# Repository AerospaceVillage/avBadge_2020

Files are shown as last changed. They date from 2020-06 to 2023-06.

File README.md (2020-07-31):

# Aerospace Village Badge 2020

This resository is to document and capture all of the engineering and design work that went into creating the [Aerospace Village](https://aerospacevillage.org) Badge for 2020.

The badge is a multifunctional design that is part SWAG, part antenna, part low level protocol interaction. In keeping with the spirit of aviation everything is as small as possible and tries to use as much of the available resources as possible.

You can even use this airplane shaped badge as an anetenna to locate real airplanes transmitting ADS-B. Additionally, you can also use it to capture data from other freqenices (i.e. ACARS) using the built in SMA to wire terminal blocks. Why stop there? You can also interact with your preferred I2C device ([bus pirate](https://learn.sparkfun.com/tutorials/bus-pirate-v36a-hookup-guide/all#introduction)) and control each of the available lighting packages. Alternatively, you could just wear it and look cool.

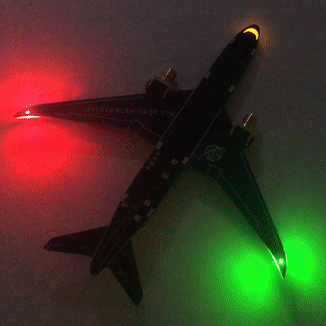
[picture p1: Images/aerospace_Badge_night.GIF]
 

## Kit Assembly

Instructions for assembing a kit can be found in the Document folder.
    
  - [Tindie Instructions](https://github.com/daneallen/avBadge_2020/blob/master/Documents/Tindie%20Instructions.pdf)
  - [Instructions sent with kit](https://github.com/daneallen/avBadge_2020/blob/master/Documents/Send%20out%20instructions.pdf)

## Arduino Programming
Using the Arduino IDE Add the correct Boards Manager URL:

    - Under File->Preferences add the following URL http://drazzy.com/package_drazzy.com_index.json
    - Then with the new Boards Maanger options select ATTinyCore

Steps:

    - Programmer - USBTinyISP
    - Clock 8MHZ
    - Burn Bootloader
    - Upload using programmer

## AVR Programming

[device permissions help](https://andreasrohner.at/posts/Electronics/How-to-fix-device-permissions-for-the-USBasp-programmer/)

[ttyACM permission](https://stackoverflow.com/questions/40951728/avrdude-ser-open-cant-open-device-dev-ttyacm0-device-or-resource-busy)

```
sudo adduser <username> dialout
$ sudo chmod a+rw /dev/ttyACM0
```

## Hardware
The ATtiny85 is programmed with the [Sparkfun Tiny AVR Programmer](https://www.sparkfun.com/products/11801) using the [SparkFun ISP Pogo Adapter](https://www.sparkfun.com/products/11591)

## Lanyard Modification
Check out the .stl files in the /sma lanyard folder that you can print to more easily turn the badge into a wearable lanyard.



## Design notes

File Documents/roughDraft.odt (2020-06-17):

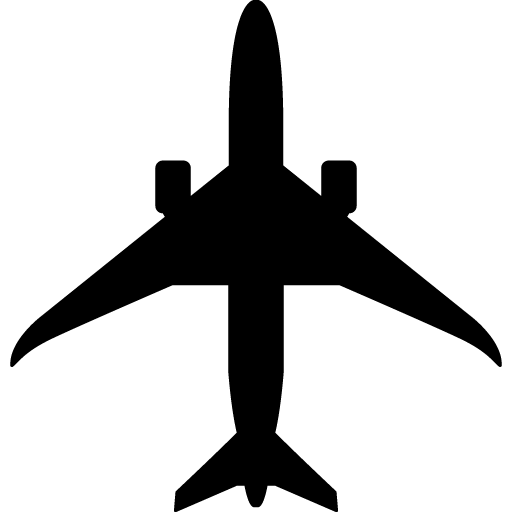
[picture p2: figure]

SMA Connector

RED LED

White Cockpit LED

All LEDs reverse mounted

PCB Antenna

Anti Collision LED - flashing

GREEN LED

Anti Collision LED - flashing

Dipole antenna setup

total length ~14cm

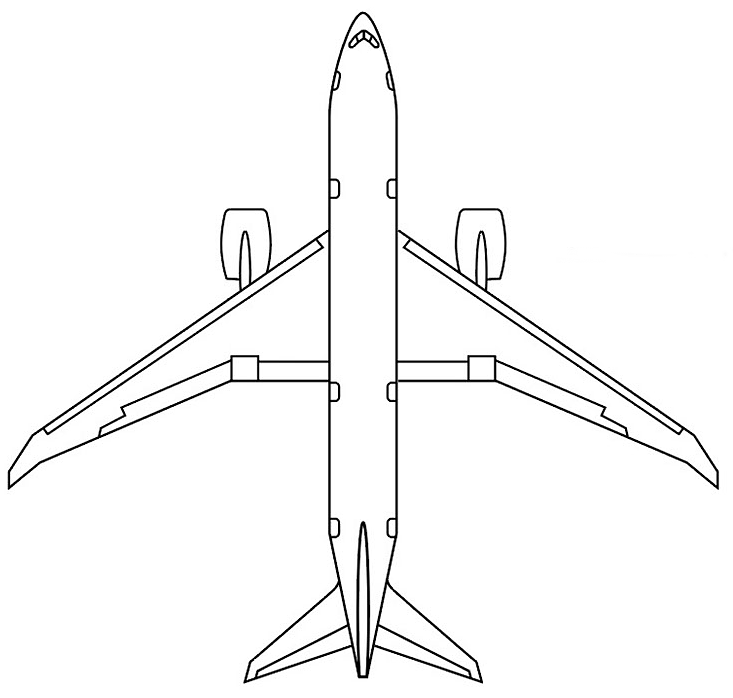
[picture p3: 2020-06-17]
Images/boeingDreamliner.png

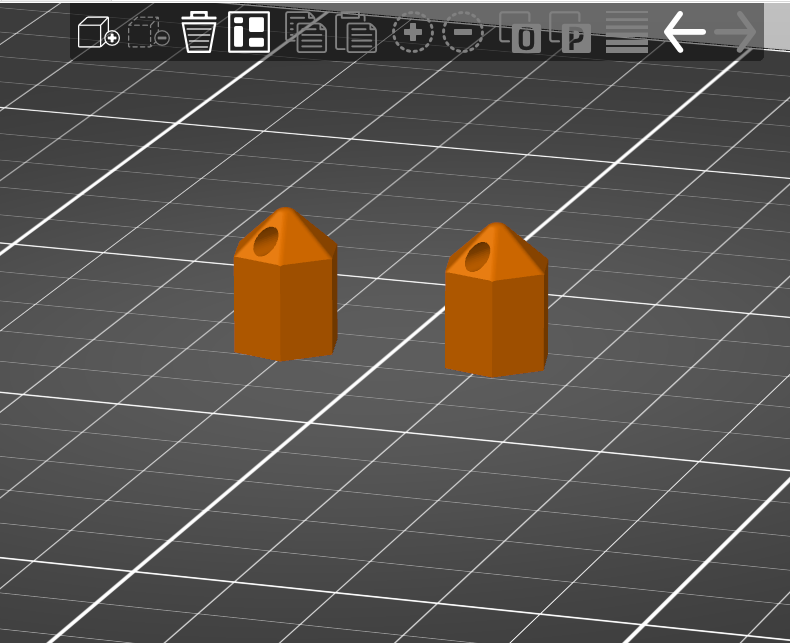
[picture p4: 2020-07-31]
sma lanyard/smaplug_caplanyard.png

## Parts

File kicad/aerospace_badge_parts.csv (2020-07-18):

Reference | Value | Notes | Footprint
BT1 | Battery_Cell |  | Battery:BatteryHolder_Keystone_3034_1x20mm
D1 | LED | Yellow - Flightdeck | sunled:XZMYK45WT-9
D2 | LED | Green – Navigation | sunled:XZDGK45WT-9
D3 | LED | Red – Navigation | sunled:XZM2CRK45WT-9
D4-D5 | LED | Anti-Collision White | aerospace_badge:led_in-s124ar
J1-J2 | Conn_01x02 | SMA Connector | aerospace_badge:linx_sma_jack_female_socket
J6-J7 | Conn_01x01_Male | Wire Terminal push button | aerospace_badge:wire_terminal_sr99s01
R1-R5 | 330 Ohms | Resistor | Resistors_SMD:R_1206_3216Metric
SW1 | SW_SPDT | Power Switch | aerospace_badge:switch_JS202011SCQN
U1 | ATtiny85-20SU | Microcontroller | Package_SO:SOIJ-8_5.3x5.3mm_P1.27mm

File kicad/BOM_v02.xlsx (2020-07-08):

Manufacturer Part Number | Manufacturer | Digi-Key Part Number | Customer Reference | Reference Designator | Packaging | Part Status | Quantity | Unit Price | Extended Price | Quantity Available | Mfg Std Lead Time | Description | RoHS Status | Lead Free Status | REACH Status
CONSMA020.062-G | Linx Technologies Inc. | 343-CONSMA020.062-G-ND |  |  | Tray | Active | 2 | 2.96 | $5.92 | 3094 | 12 Weeks | CONN SMA FML EDGE MNT 0.062" PCB | ROHS3 Compliant | Lead free | Not Available
XZM2CRK45WT-9 | SunLED | 1497-1332-1-ND |  |  | Cut Tape (CT) | Active | 1 | 0.66 | $0.66 | 1772 | 12 Weeks | LED RED CLEAR 2PLCC SMD | ROHS3 Compliant | Lead free | REACH Unaffected
XZDGK45WT-9 | SunLED | 1497-1337-1-ND |  |  | Cut Tape (CT) | Active | 1 | 0.74 | $0.74 | 98154 | 12 Weeks | LED GREEN CLEAR 2PLCC | ROHS3 Compliant | Lead free | Not Available
XZMYK45WT-9 | SunLED | 1497-1334-1-ND |  |  | Cut Tape (CT) | Active | 1 | 0.54 | $0.54 | 21238 | 12 Weeks | LED YELLOW CLEAR 2PLCC SMD | ROHS3 Compliant | Lead free | REACH Unaffected
RC1206FR-07330RL | Yageo | 311-330FRCT-ND |  |  | Cut Tape (CT) | Active | 5 | 0.1 | $0.50 | 31990 | 24 Weeks | RES SMD 330 OHM 1% 1/4W 1206 | ROHS3 Compliant | Lead free | REACH Unaffected
ATTINY85-20SUR | Microchip Technology | ATTINY85-20SURCT-ND |  |  | Cut Tape (CT) | Active | 1 | 1.19 | $1.19 | 8552 | 17 Weeks | IC MCU 8BIT 8KB FLASH 8SOIC | ROHS3 Compliant | Lead free | REACH Unaffected
3034 | Keystone Electronics | 36-3034-ND |  |  | Bulk | Active | 1 | 0.31 | $0.31 | 5529 | 6 Weeks | BATTERY RETAINER COIN 20MM SMD | ROHS3 Compliant | Lead free | REACH Unaffected
IN-S124ARUW | Inolux | 1830-1119-1-ND |  |  | Cut Tape (CT) | Active | 2 | 0.41 | $0.82 | 17759 | 6 Weeks | LED WHITE CLEAR 1204 SMD | ROHS3 Compliant | Lead free | Not Available
SR99S01VBNN00G7 | METZ CONNECT USA Inc. | 1849-1167-1-ND |  |  | Cut Tape (CT) | Active | 2 | 1.16 | $2.32 | 6098 | 15 Weeks | TERM BLOCK 1POS SIDE ENTRY PCB | RoHS Compliant | Lead free | Not Available
JS202011SCQN | C&K | 401-2002-1-ND |  |  | Cut Tape (CT) | Active | 1 | 0.6 | $0.60 | 30511 | 13 Weeks | SWITCH SLIDE DPDT 300MA 6V | ROHS3 Compliant | Lead free | REACH Unaffected

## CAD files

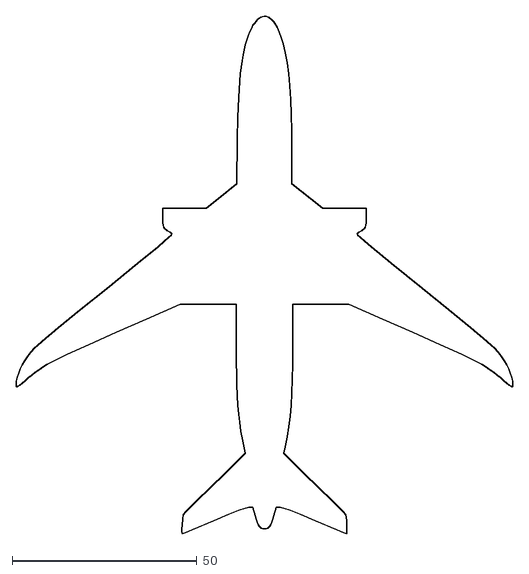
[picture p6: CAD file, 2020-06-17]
Images/boeing787.dxf
134.3 x 140.0

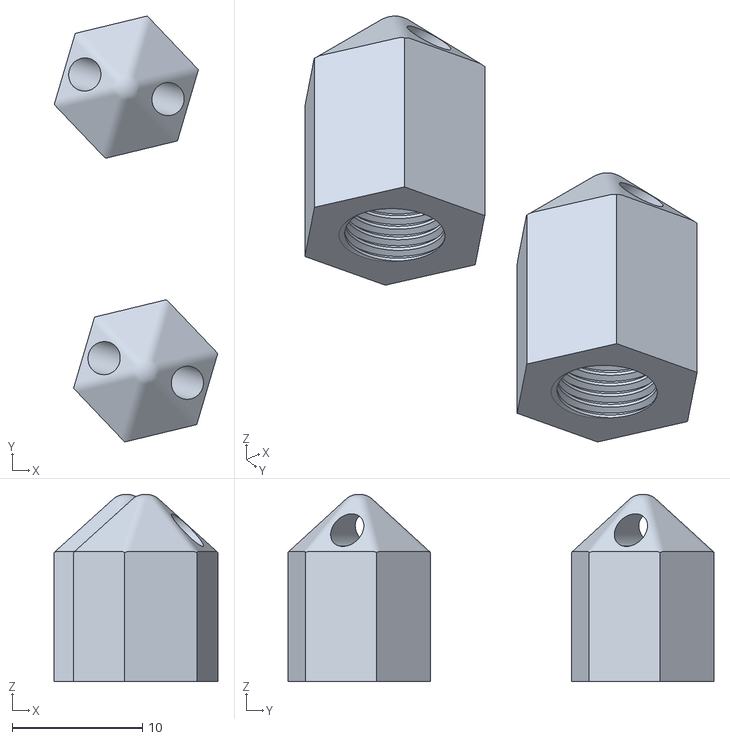
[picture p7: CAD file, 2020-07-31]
sma lanyard/smaplug_aero.stl
12.5 x 32.7 x 14.4

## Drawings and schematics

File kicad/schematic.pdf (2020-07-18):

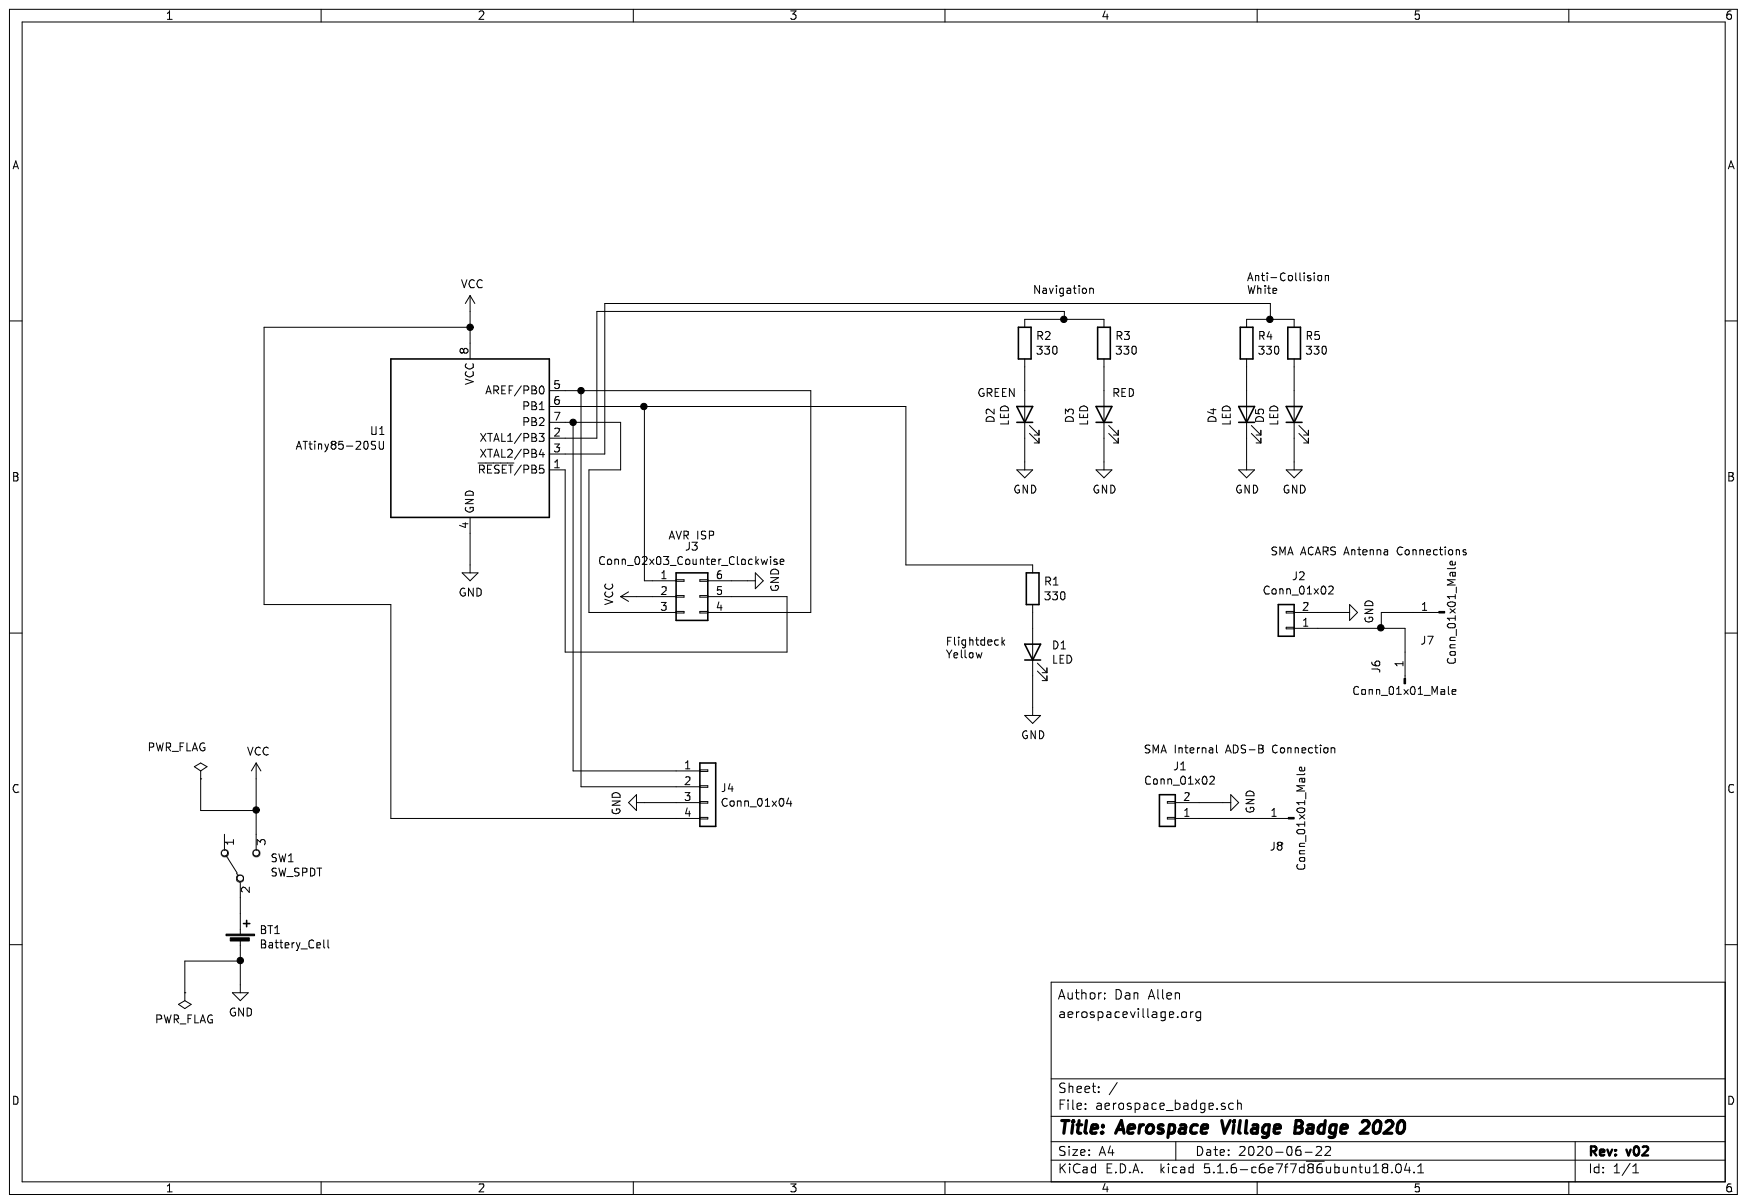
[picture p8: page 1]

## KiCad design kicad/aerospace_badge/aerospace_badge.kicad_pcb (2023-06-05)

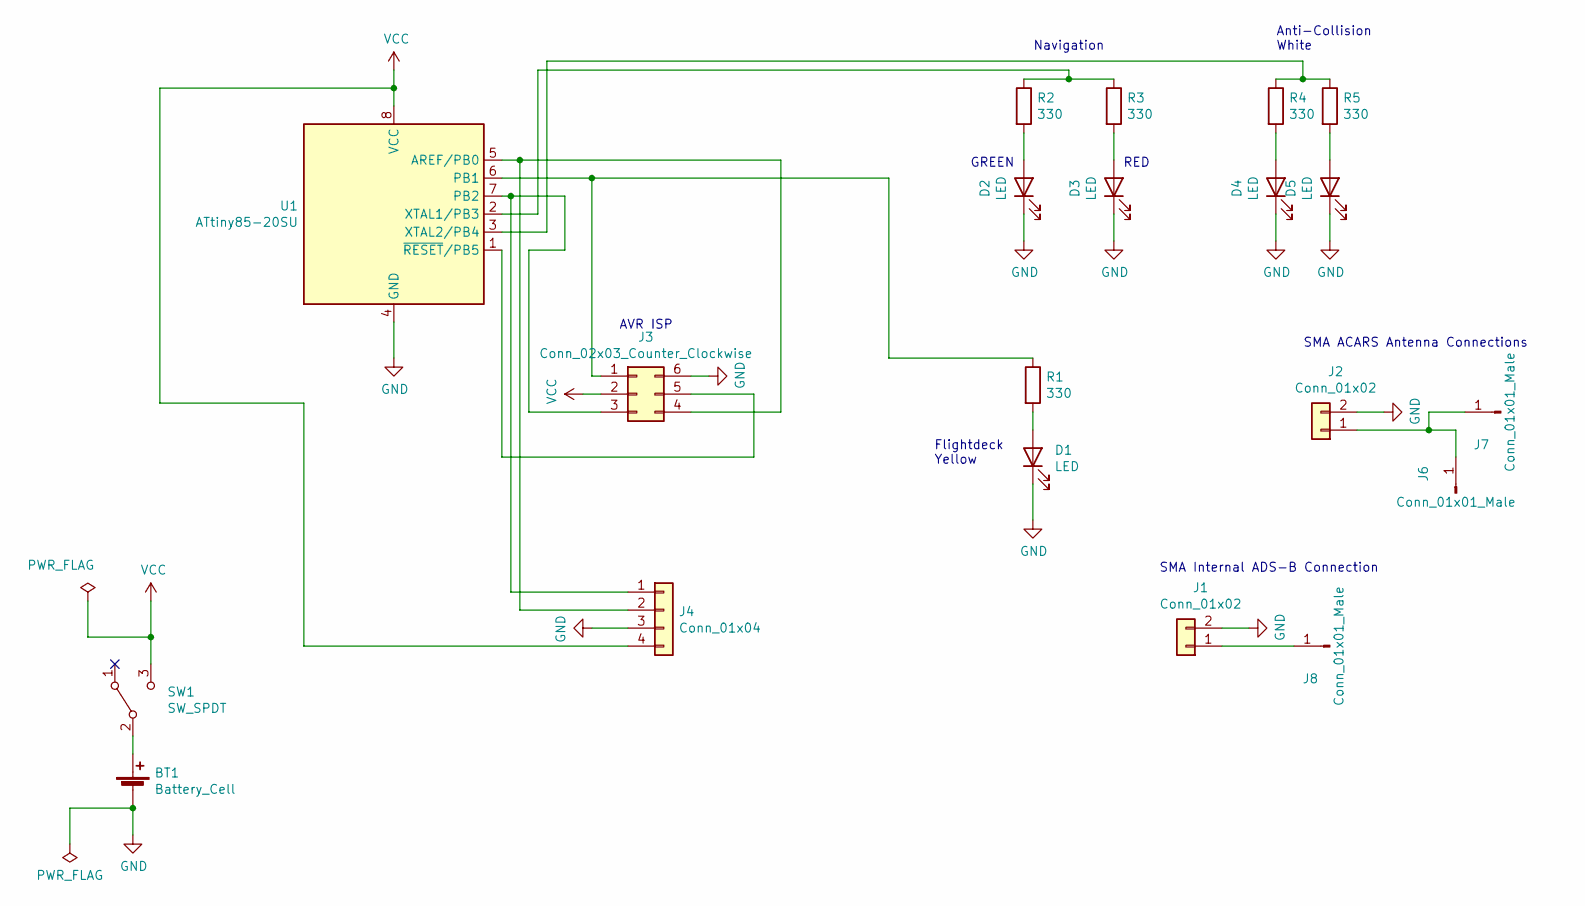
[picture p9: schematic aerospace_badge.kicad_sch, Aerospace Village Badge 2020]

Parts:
BT1: Battery_Cell; BatteryHolder_Keystone_3034_1x20mm
D1: LED; XZMYK45WT-9
D2: LED; XZDGK45WT-9
D3: LED; XZM2CRK45WT-9
D4, D5: LED; led_in-s124ar
J1, J2: Conn_01x02; linx_sma_jack_female_socket
J3: Conn_02x03_Counter_Clockwise; isp_pad
J4: Conn_01x04; PinHeader_1x04_P2.54mm_Vertical
J6, J7: Conn_01x01_Male; wire_terminal_sr99s01
J8: Conn_01x01_Male; badge_v02
R1, R2, R3, R4, R5: 330; R_1206_3216Metric
SW1: SW_SPDT; switch_JS202011SCQN
U1: ATtiny85-20SU; SOIJ-8_5.3x5.3mm_P1.27mm

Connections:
GND: BT1.2 (-), D1.1 (K), D2.1 (K), D3.1 (K), D4.1 (K), D5.1 (K), J1.2, J2.2, J3.6, J4.3, U1.4 (GND)
unnamed: BT1.1 (+), SW1.2 (B)
unnamed: D1.2 (A), R1.2
unnamed: D2.2 (A), R2.2
unnamed: D3.2 (A), R3.2
unnamed: D4.2 (A), R4.2
unnamed: D5.2 (A), R5.2
unnamed: J1.1, J8.1
unnamed: J2.1, J6.1, J7.1
unnamed: J3.1, R1.1, U1.6 (PB1)
unnamed: J3.3, J4.1, U1.7 (PB2)
unnamed: J3.4, J4.2, U1.5 (AREF/PB0)
unnamed: J3.5, U1.1 (~RESET/PB5)
unnamed: R2.1, R3.1, U1.2 (XTAL1/PB3)
unnamed: R4.1, R5.1, U1.3 (XTAL2/PB4)
VCC: J3.2, J4.4, SW1.3 (C), U1.8 (VCC)

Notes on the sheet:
SMA Internal ADS-B Connection
Anti-Collision White
AVR ISP
Navigation
SMA ACARS Antenna Connections
Flightdeck Yellow
RED
GREEN

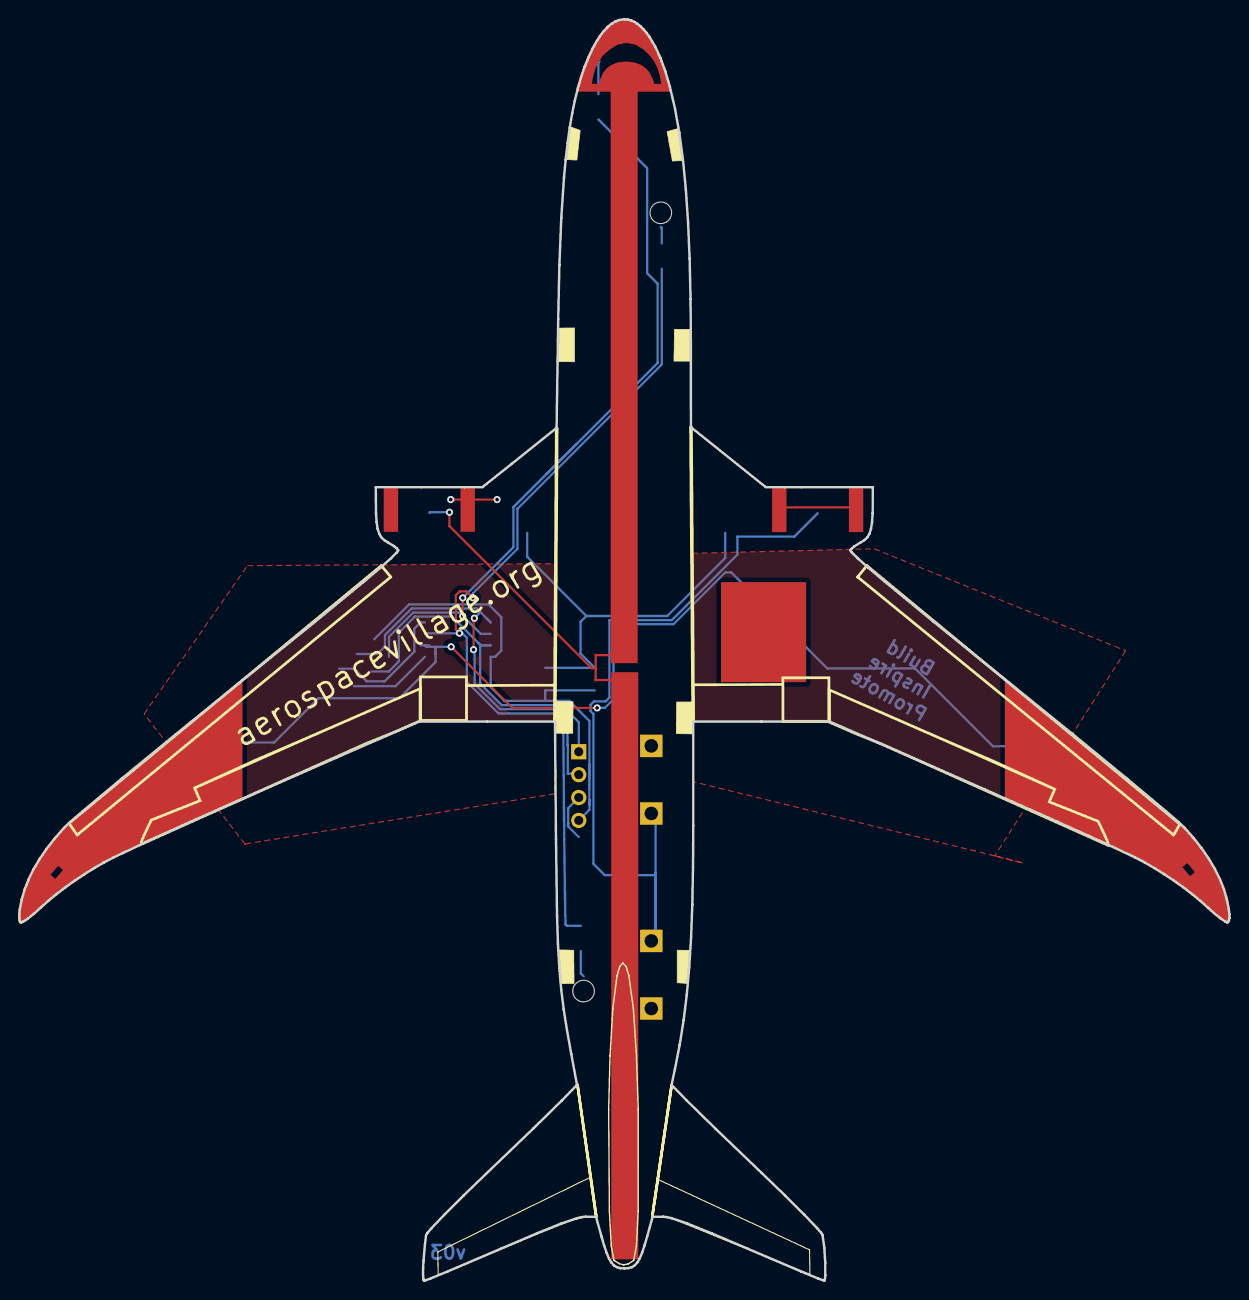
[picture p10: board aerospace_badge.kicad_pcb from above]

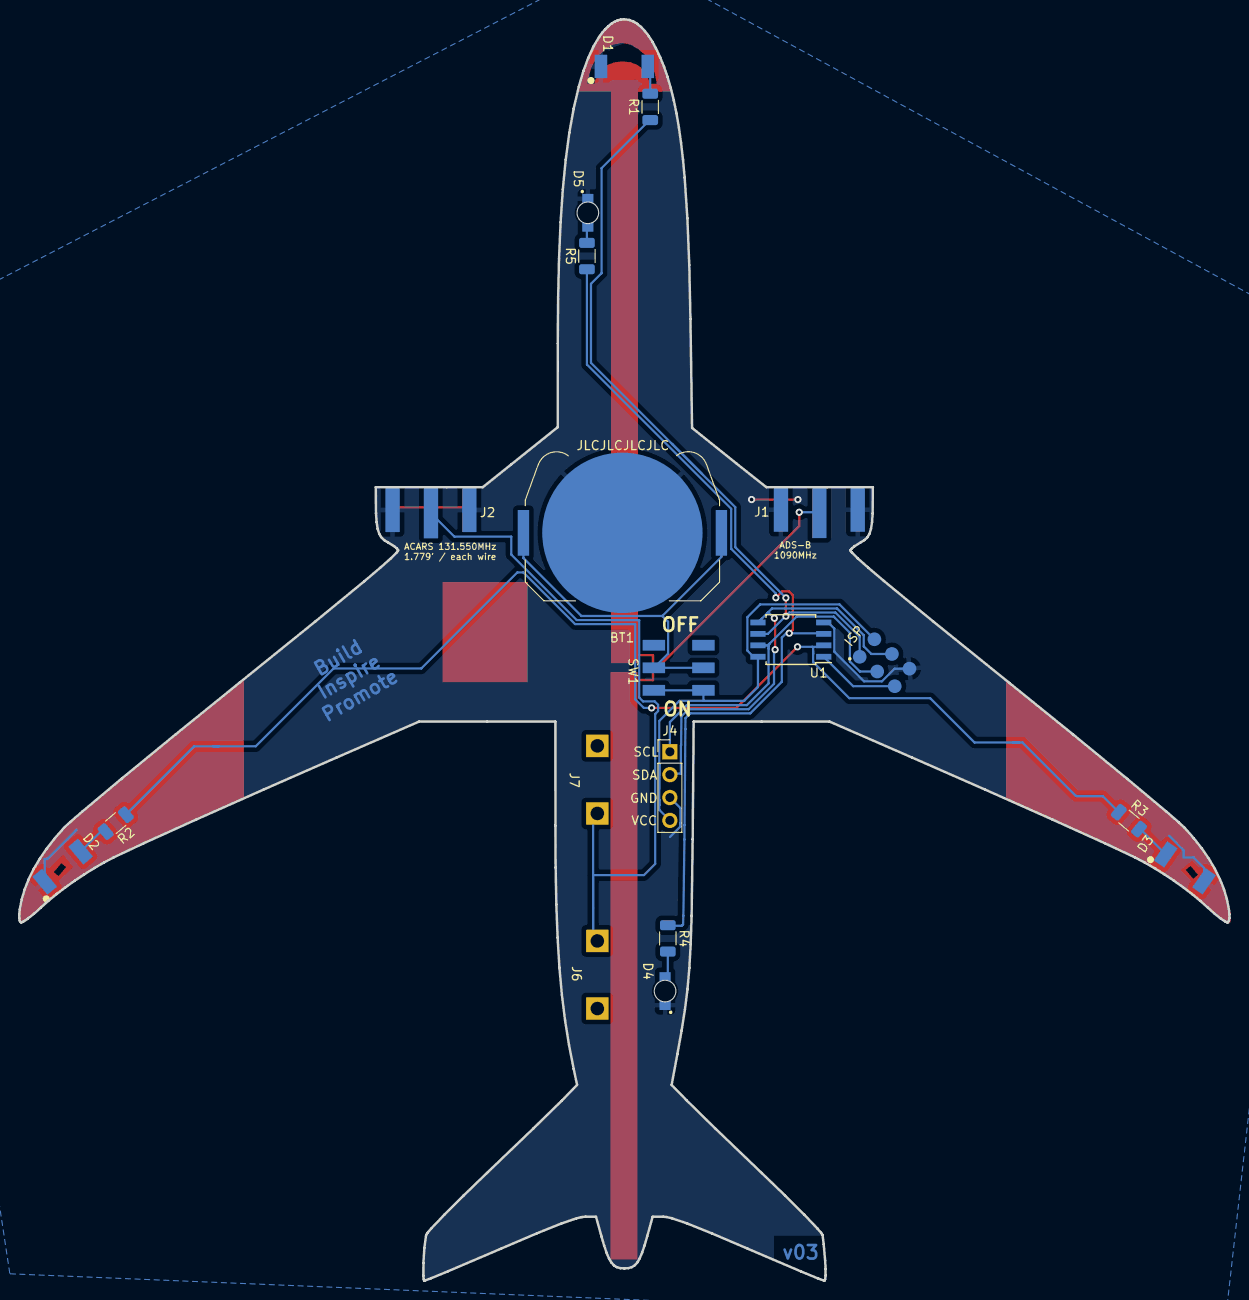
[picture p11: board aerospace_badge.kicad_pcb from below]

Board: 2 copper layers, 134.3 x 140.0 mm, 20 parts (17 on the bottom side), 16 nets.

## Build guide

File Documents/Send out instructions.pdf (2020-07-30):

Fuselage – Front
- D1-Yellow, orientation mark le7
- D5-White, orientation “T” pointing away from resistor
- R1 and R5
Le7 Wing (as seen from bottom with battery holder)
- D2-Green, orientation mark AWAY from resistor
- R2
Right Wing (as seen from bottom with battery holder)
- D3-Red, orientation mark
TOWARD resistor
- R3

Fuselage - A7
- D4-White, orientation “T” pointing away from resistor
- R4
- J6 & J7
Fuselage - Midsection
- SW1 and BT1
- U1, orientation mark
- 2x SMA connectors
- https://www.4ndie.com/
products/aero_village/
aerospace-village-badge-fordc28-diy-kit/

Fuselage – Front
- D1-Yellow, orientation mark le7
- D5-White, orientation “T” pointing away from resistor
- R1 and R5
Le7 Wing (as seen from bottom with battery holder)
- D2-Green, orientation mark AWAY from resistor
- R2
Right Wing (as seen from bottom with battery holder)
- D3-Red, orientation mark
TOWARD resistor
- R3

Fuselage - A7
- D4-White, orientation “T” pointing away from resistor
- R4
- J6 & J7
Fuselage - Midsection
- SW1 and BT1
- U1, orientation mark
- 2x SMA connectors
- https://www.4ndie.com/
products/aero_village/
aerospace-village-badge-fordc28-diy-kit/

Fuselage – Front
- D1-Yellow, orientation mark le7
- D5-White, orientation “T” pointing away from resistor
- R1 and R5
Le7 Wing (as seen from bottom with battery holder)
- D2-Green, orientation mark AWAY from resistor
- R2
Right Wing (as seen from bottom with battery holder)
- D3-Red, orientation mark
TOWARD resistor
- R3

Fuselage - A7
- D4-White, orientation “T” pointing away from resistor
- R4
- J6 & J7
Fuselage - Midsection
- SW1 and BT1
- U1, orientation mark
- 2x SMA connectors
- https://www.4ndie.com/
products/aero_village/
aerospace-village-badge-fordc28-diy-kit/

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

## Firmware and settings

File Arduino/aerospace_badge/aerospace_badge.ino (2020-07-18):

/**
 *
 * Aerospace Badge 2020
 * 
 * This is the code for the Aerospace Village Badge DEF CON 2020.
 * 
 * The code for the badge provides an I2C interface to the following 
 * 3 lighting packages: 
 *  1. Navigation Lights (Red and Green)
 *  2. Flightdeck Lights (Yellow)
 *  3. Anti-Collision Lights (White)
 *  
 *  This code is targeting the Attiny85 MCU and uses the TinyWire package
 *  https://github.com/rambo/TinyWire
 *  
 *  
 *  I2C Slave Address 0x44
 *  
 * Author: Dan Allen
 * Date: 14 June 2020
 * Version: 1.0
 *
 **/
 
 #define I2C_SLAVE_ADDRESS 0x44 // the 7-bit address
// Get this from https://github.com/rambo/TinyWire

#include <TinyWireS.h>

// The default buffer size
#ifndef TWI_RX_BUFFER_SIZE
#define TWI_RX_BUFFER_SIZE ( 16 )
#endif
 
#define NAV_PIN 3
#define FLIGHTDECK_PIN 1
#define ANTI_COLLISION_PIN 4
 
// Allow the user to change the lights being on/off
volatile boolean nav_lights = true;
volatile int flightdeck_lights = 50;
volatile boolean anti_collision_lights = true;

unsigned long previousMillis = 0;  // stores last state time for anti-collision lights


const int anti_collision_ON_TIME = 40;
const int anti_collision_OFF_TIME = 1800;
boolean anti_collision_ON_STATE = true;

char msg[154] = "Aerospace Village\n\nBUILD - INSPIRE - PROMOTE\n\n Send us an email at village@aerospacevillage.org with the subject badge and tell us what you thought!";
int msg_len = 154;
int msg_index = 0;


void requestEvent()
{
    TinyWireS.send(byte(msg[msg_index]));
  msg_index++;
  if(msg_index > msg_len){
    msg_index = 0;
  }
}

void receiveEvent(uint8_t howMany)
{
  //Sanity check, only looking for 1 byte of passed in data
  if( howMany != 1){
    return;
  }
  
  int value = TinyWireS.receive();
  if( value == 1){
    nav_lights = !nav_lights;
  }else if ( value == 2){
    anti_collision_lights = !anti_collision_lights;    
  }else if ( value == 3){
    flightdeck_lights = 0;
  }else{
    flightdeck_lights = value;
  }
}


void setup()
{
  pinMode(NAV_PIN, OUTPUT);
  pinMode(FLIGHTDECK_PIN, OUTPUT);
  pinMode(ANTI_COLLISION_PIN, OUTPUT);

  TinyWireS.begin(I2C_SLAVE_ADDRESS);
  TinyWireS.onReceive(receiveEvent);
  TinyWireS.onRequest(requestEvent);
}

/*
* Helper function to handle the aysmmetric timing of the anti-collision lights.
* To create the desired timing the lights are pulsed in a quick burst.
*/
void antiCollisionLights()
{
  unsigned long currentMillis = millis();
  
  if(anti_collision_ON_STATE){
    if(currentMillis >= previousMillis + anti_collision_ON_TIME){
      anti_collision_ON_STATE = !anti_collision_ON_STATE;
      previousMillis = currentMillis;
      if(anti_collision_lights){
        digitalWrite(ANTI_COLLISION_PIN, LOW);
      }
    }
  }else{
    if(currentMillis >= previousMillis + anti_collision_OFF_TIME){
      anti_collision_ON_STATE = !anti_collision_ON_STATE;
      previousMillis = currentMillis;
      if(anti_collision_lights){
        digitalWrite(ANTI_COLLISION_PIN, HIGH);
      }
    }
  }   
 }
 
void loop()
{
  digitalWrite(NAV_PIN, nav_lights);
  analogWrite(FLIGHTDECK_PIN, flightdeck_lights);
  antiCollisionLights();

  TinyWireS_stop_check();
}
   

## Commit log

2020-06-17 Initial repo creation
    Organized and created the repo so that others can collaborate
    [Bom.xlsx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]
2020-06-17 updated footprints per new datasheets.
    [aerospace_badge.kicad_pcb, aerospace_badge.sch]
2020-06-19 updated image for larger antenna and flightdeck front copper.
2020-06-19 svg2mod changes of svg to footprint.
2020-06-19 updated BOM for v02
    [BOM_v02.csv]
2020-06-19 updated bom from csv to xls
    [BOM_v02.csv, BOM_v02.xlsx]
2020-06-22 updated, needs another check prior to fabrication.
    [aerospace_badge.kicad_pcb, aerospace_badge.sch]
2020-06-22 open windows weren't saved... they are now.
    [aerospace_badge.kicad_pcb]
2020-06-22 new datasheet and closing checks.
    [aerospace_badge.kicad_pcb]
2020-06-22 subtle distance added between wire terminal connectors.
    [aerospace_badge.kicad_pcb]
2020-06-22 nearly complete, small checks/tweaks ongoing.
    [aerospace_badge.kicad_pcb]
2020-06-22 final review with new gerbers and zip.
    [aerospace_badge-B_Cu.gbl, aerospace_badge-B_Mask.gbs, aerospace_badge-B_Paste.gbp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]
2020-06-22 not even sure what the difference is/was.
    [aerospace_badge.kicad_pcb]
2020-06-22 f.silk fueslage line not as thick on right vs. left. Fixed.
    [aerospace_badge.kicad_pcb]
2020-06-23 jlcpcb rejected because traces too close to edge, trace refactor.
    [aerospace_badge-B_Cu.gbl, aerospace_badge-B_Mask.gbs, aerospace_badge-B_Paste.gbp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]
2020-06-23 including new gerber zip bundle.
2020-07-08 updated BOM from digikey
    [BOM_v02.xlsx]
2020-07-08 organizing and finalizing.
    [Bom.xlsx, defconLogo.dxf]
2020-07-09 preserve original gerber zip but move away from main folder for posterity.
2020-07-18 including helpful assembly documents.
    [aerospace_badge_parts.csv]
2020-07-30 adding assembly isntructions.
2020-07-31 SMA caps to add jumper ring for lanyard
    Print at .2mm or finer. It's a tight initial turn, but once on, easy to screw on and off. Use a jumper ring and clip lanyard with lobster clasp of your choice.
    [smaplug_aero.stl]
2023-06-05 cosmetic updates and KiCad version update, footprint inclusions
    [aerospace_badge.kicad_pcb, aerospace_badge.kicad_sch]
